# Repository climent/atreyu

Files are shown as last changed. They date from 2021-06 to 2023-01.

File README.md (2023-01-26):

# Atreyu keyboard

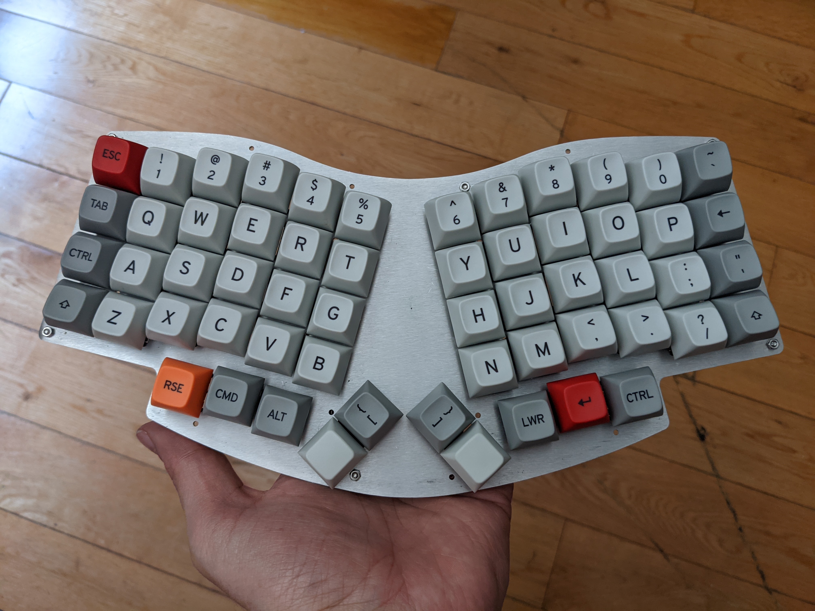
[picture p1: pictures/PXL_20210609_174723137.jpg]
A picture of the original, handwired Atreyu The original, handwired Atreyu keyboard

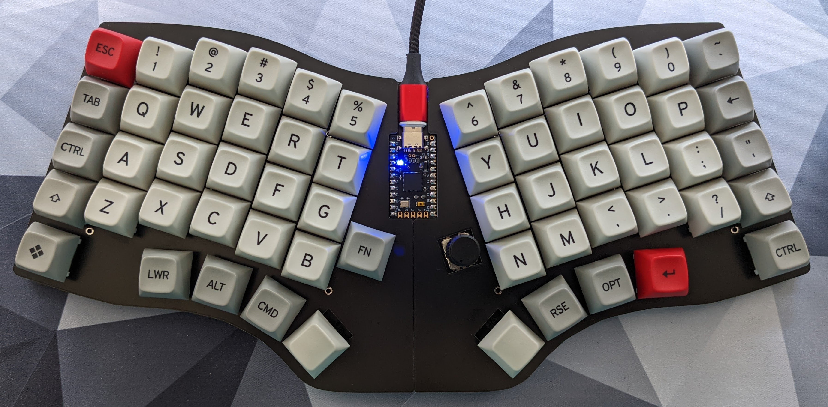
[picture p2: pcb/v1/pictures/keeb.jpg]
A picture of the Atreyu (v1) The Atreyu v1 keyboard

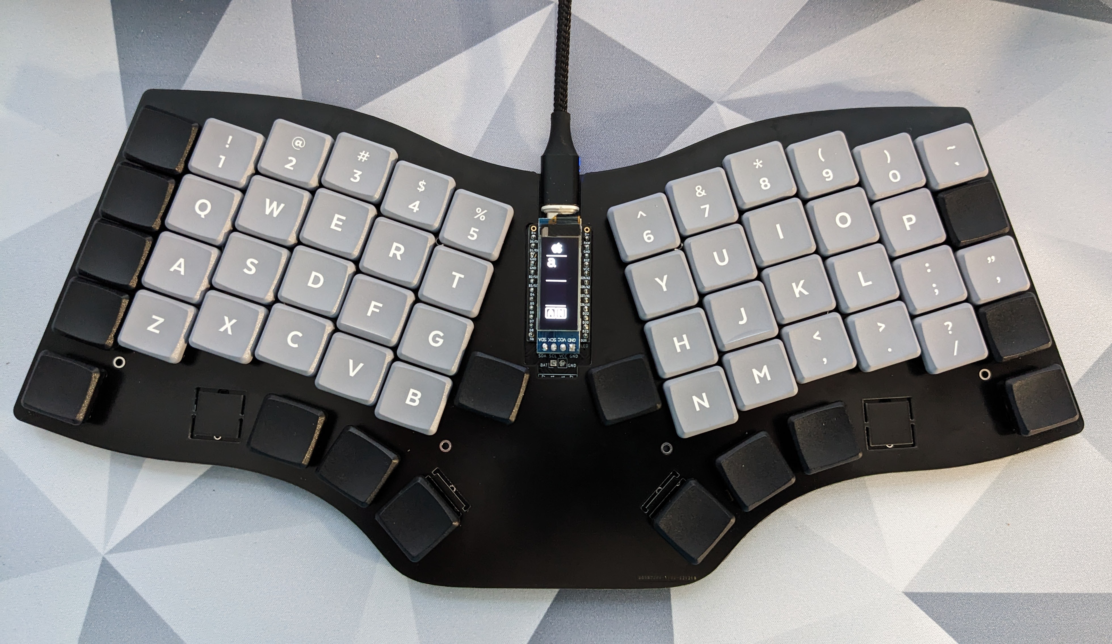
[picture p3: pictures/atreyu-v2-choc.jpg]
A picture of the Atreyu v2 Choc The Atreyu v2 Choc keyboard

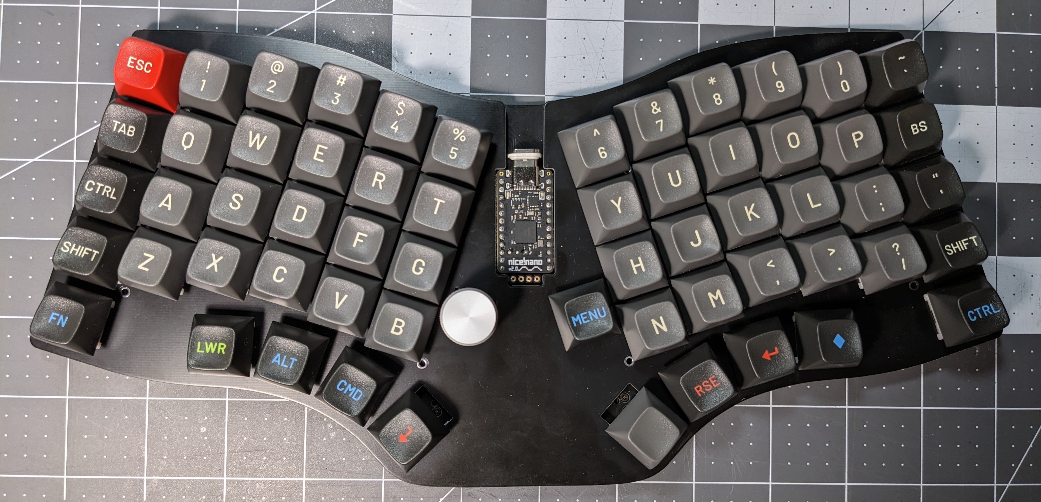
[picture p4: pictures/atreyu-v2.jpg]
A picture of the Atreyu v2 MX The Atreyu v2 Choc keyboard


It all started with a handwired Lily58fied version of the Atreis keyboard.

Based on [Dekonnection's Atreis keyboard design files](https://github.com/dekonnection/atreis),
modified to achieve the same layout in a single-piece form-factor.

## Why ?

Because the Atreis is the most convenient keyboard to take when on the go, but I thought i needed a couple of extra keys, like the Lily58.

## What happened next?

Learning KiCad was fun, and I ended up creating a new version of the keyboard on a PCB, with the option of having they inner keys as rotary encoders, and with two additional keys at the bottom of the outer columns to be pressed with the palm. In all honesty I think I could do with less keys, but using the same amount of pins in the micro controller I could have all 60 keys in the matrix defined.

In retrospect I think I could remove some keys and be happy and productive, but at the same time I enjoyed doing the design, and I like it.

## Why this name ?

Because it looks a lot like the Atreis keyboard, but with the Lily58 layout.

## How do I build one ?

You can find a [PCB](http://github.com/climent/atreyu/tree/main/pcb) for it. The board has been fully tested and the firmware is functional out of the box. A build guide is under construction.

## Can I do the handwired version?

Sure thing! The SVG files are [available](pcb/handwired/). The wiring is quite straightforward: all rows are independent, and columns are combined together across both sides (columns are connected from outside to inside). You can [check this picture](pictures/atreyu-wired.jpg?raw=true "The wires"). You just have to flash the right firmware with the right keymap, all of which are available from the link below.

# Firmware

You can find my copy of the keyboard mapping [here.](http://github.com/climent/qmk_firmware/tree/climent/keyboards/atreyu/)

There are 3 different revisions: handwired, rev1 and rev2, depending of the board you are building .

You can also find the keyboard configuration to get a working firmware for rev1 and rev2 in the [main QMK tree](http://github.com/qmk/qmk_firmware/tree/master/keyboards/atreyu/).

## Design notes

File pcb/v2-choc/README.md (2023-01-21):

# Atreyu V2 choc keyboard

A picture of the Atreyu V2 choc The Atreyu keyboard

# Changes from V1

* New options for MCUs:
  * Pro Micro: with this MCU the functionality of the keyboard is only reduced by not being able to use encoders.
  * Elite-C, Elite-Pi, Puchi, Frood: all the functioinality, i.e., OLED, encoders, all keys.
  * Nice!Nano v2: all functionality plus wireless! (Some restrictions apply)

| MCU | OLED |Encoders | Bluetooth (ZMK) | LEDs |
|---|---|---|---|---|
|ProMicro | ✅ | 🚧 | | ✅ |
|Elite-C  | ✅ | ✅ | | ✅ |
|nice!nano| 🚧 | ✅ | ✅ | ✅ |

* OLED pins for a 32x128 screen over the MCU
* Space for a battery, with power kill switch and pins for soldering the battery to the PCB, currently for a 500mAh
  * Different versions of the PCB will be released for different battery sizes.
* 5 underglow LED (SK6812Mini-E slots) as status indicators.

The new Rev2 revision is not pin-compatible with Rev1.

Due to the fact that some pins are shared across the OLED, the encoders and the LEDs, some configurations require sacrificing some features in favour of others. E.g., in a board with OLED and LEDs, one can only have one encoder.

NOTE: Elite-pi, Frood, and similar rp2040-based boards work the same way as the Elite-C board, as they have the same number of pins available.

# Firmware

You can find my copy of the keyboard mapping [here.](http://github.com/climent/qmk_firmware/tree/master/keyboards/atreyu/)

QMK firmware is available upstream, under the rev2 folder.

ZMK configuration for the Nice!nano board is available [here](https://github.com/climent/zmk-config)

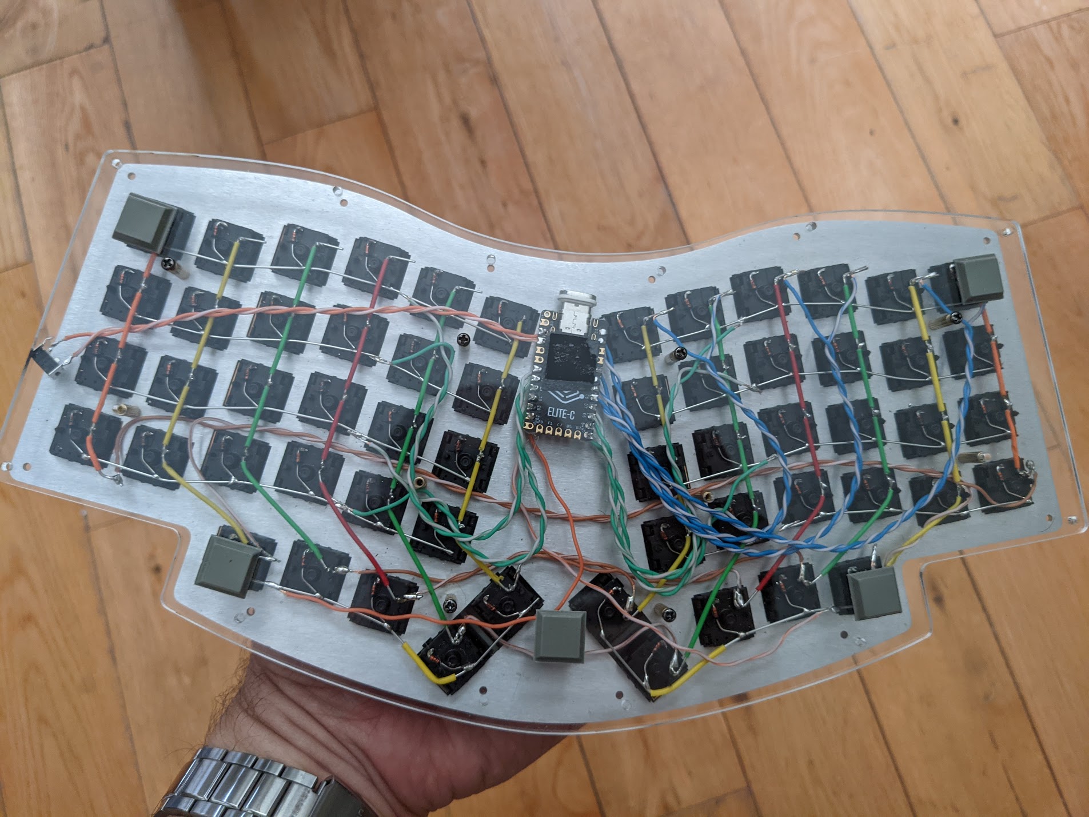
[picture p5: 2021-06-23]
pictures/atreyu-wired.jpg

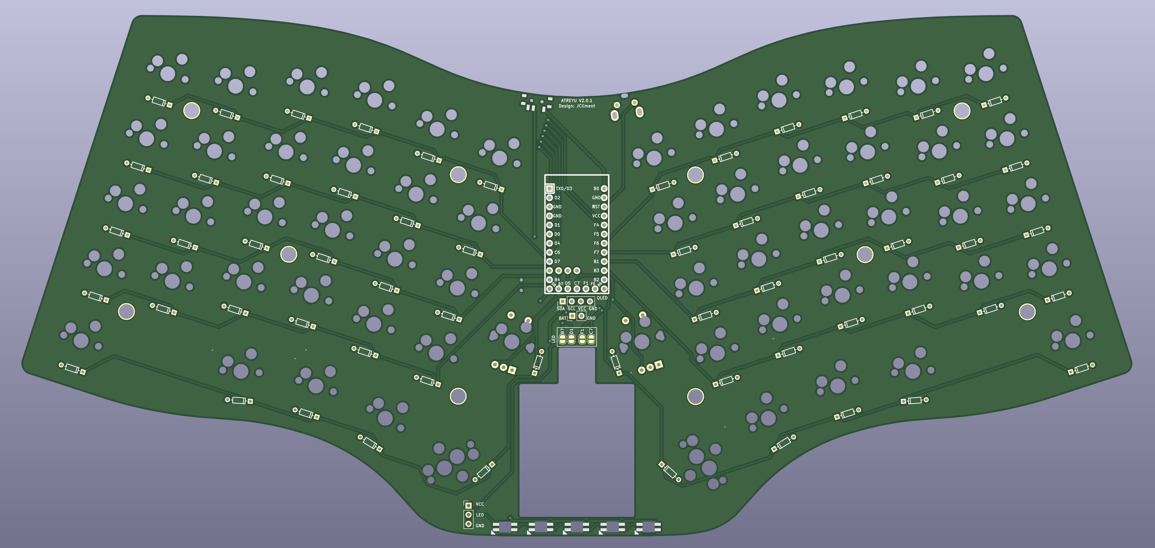
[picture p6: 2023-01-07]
pcb/v2/pictures/top.png

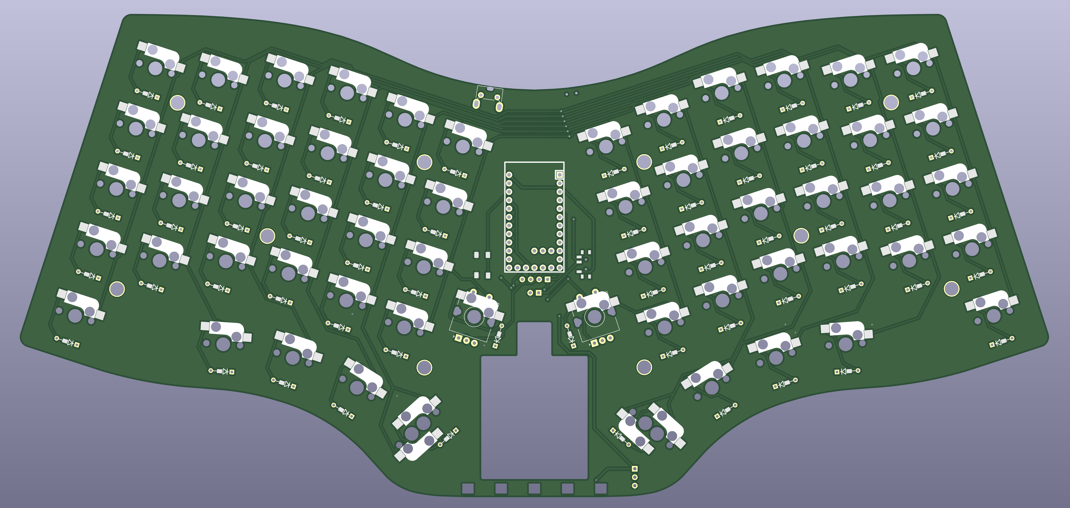
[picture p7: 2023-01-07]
pcb/v2/pictures/bottom.png

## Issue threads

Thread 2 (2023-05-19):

gerbers files for V2 (none-choc)

maxyurk, 2023-05-19:
Hi

First of all I'd like to thank you for this awesome open source keyboard.
I'm interested in building one.
My ask is if it would be possible to include the gerbers for the V2 under the sources/releases. I'm not experienced with KiCad and when I tried to create them I got an issue I couldn't resolve on my own.

Also if you're interested I can help out creating a github page for this project. I noticed a stale branch for it in the repo. https://docusaurus.io/ is a pretty good option I'm familiar with.

Thanks in advance.

climent, 2023-05-21:
Gerber files for v2 have been added to the repo. Enjoy!

maxyurk, 2023-08-04:
Thank you. It turned out great. Really happy with it.
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

climent, 2023-08-04:
Looks really nice! Hope you enjoy it!

Closed 2023-05-21.

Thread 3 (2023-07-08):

Rotary Encoder Troubleshooting

TimCummings, 2023-07-08:
Hello, and thanks for the fantastic keyboard design!

This isn't exactly an "issue", I'm just having some trouble getting rotary encoders to work and wanted to see if you had any suggestions. I have an Atreyu v2 choc PCB with a nice!nano and [EC12 encoders](https://tech.alpsalpine.com/e/products/detail/EC12E2440301/). I have the two `CONFIG_EC11` lines uncommented in the top level `atreyu.conf` file. And I can't get the encoders to do anything (I've tried volume +/- and page up/down so far; I have the same key codes on other switches and they work as expected there.)

If it were a switch, I'd check continuity across the pins with the switch pressed, but I'm less sure how to start troubleshooting a rotary encoder.

Also, the underglow status LEDs - are they used at all by default or do I need to add something in the firmware for those?

climent, 2023-07-11:
Let me figure it out and i will get back to you.

climent, 2023-07-14:
First of all, for the encoders to work with a nice!nano board, the 3 extra pins in the middle of the board need to be connected. Did you connect those?

I am right now testing support for the encoder on the right, as I had only configured the code for the encoder on the left. I will let you know once it is working correctly.

TimCummings, 2023-07-15:
> First of all, for the encoders to work with a nice!nano board, the 3 extra pins in the middle of the board need to be connected.

Is that pins 101, 102, & 107 in the screenshot here? https://nicekeyboards.com/docs/nice-nano/

climent, 2023-07-15:
Correct. The routing of the tracks needs those pins. The default configuration in the zmk-config repository here is set for the encoder on the left side.

https://github.com/climent/zmk-config/tree/5e345b4ee15ec3eaf14a35d0d8089bc64e64358b

After that I made some changes that broke the board, but I have not had the time to continue investigating.

TimCummings, 2023-07-15:
That was the issue: I overlooked those three pins. Sorry about that; thanks for your help!

The left is working great; the right works but is a little funky (seems to send both presses with a slight delay in the middle.) I'll fiddle with it some and comment back if I have any success. I was just stuck when I couldn't get either of them to do anything - which makes sense if they weren't even connected to the controller! :facepalm:

Closed 2023-07-15.

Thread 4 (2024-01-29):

Is a build guide still in the works?

Richiban, 2024-01-29:
I've started a build of the Atreyu and it's the first keyboard I'll be building from scratch.

I've got the PCB and have soldered on the hotswap sockets and the socket for the controller; I'm a bit lost, however, with everything else. I've got a nice!nano because I'm planning a wireless build but I'm happy to stick with wired to get it up and running and will upgrade it later. Apologies if these questions are answerable by looking at the KiCad files, but that's rather beyond my ability at the moment.

For the wired version I need to know:
* Where should I put the reset switch? No switch is visible in the photos of the complete keyboard.
* What kind of diodes do I need? The PCB seems to have symbols for SMD diodes on one side of the board and through-hole on the other. Do I need both?
* The socket for the controller seems to have more pins than exist on the nice!nano (i.e. there's one shorter bank on the "bottom" of the controller that the nice!nano doesn't have). Am I giving anything up using nice!nano?

Eventually, to make it wireless, I need to know:
* Where do I put the battery switch?
* Where do I put the battery connector?

Thank you very much for releasing this keyboard design; it's by far my favourite I've ever seen! I currently have a pre-built Sofle that I love, but I'm looking to go unsplit / unibody.

climent, 2024-01-29:
Hi Richard.

First of all, thanks for reaching out. I understand building your first
keyboard may be a daunting task, and i will try to help you as much as i
can.

What version of the PCB did you use? The latest one (2.0.1) should be the
one to use, as it fixed a couple of bugs on the previous ones. Can you
confirm you have that one?

For the reset switches, there are 2 options: a lateral push switch,
available at
https://splitkb.com/collections/keyboard-parts/products/reset-buttons, or a
flat switch, like this one: https://www.digikey.ie/short/ntjm0mnn

The side button goes here:

[image: Screenshot 2024-01-29 at 14.08.24.png]

While the flat button goes here:

[image: Screenshot 2024-01-29 at 14.08.55.png]

There is also a battery switch, available from here:
https://splitkb.com/products/wireless-controller-expansion-bundle

It goes either here:

[image: Screenshot 2024-01-29 at 14.10.02.png]

Or here:

[image: Screenshot 2024-01-29 at 14.10.21.png]

I recommend using the internal ones, as they are accessible from the 2
holes in the bottom plate, and they look nicer in my opinion.

The diodes are standard 1N4148W signal diodes, available here:
https://splitkb.com/collections/keyboard-parts/products/smd-diodes

They can be soldered on the bottom side of the board, with the side of the
line pointing in the direction of the arrow. The Soufflé build guide
https://github.com/climent/SouffleKeyboard/blob/main/docs/build_guide.md
has some photos on how to set them up.

The 3 extra pins in the middle of the nice nano are for rotary encoders,
but they are currently broken in the ZMK software, so you don't miss much,
right now.

If you want to have the encoders, then you have to move the battery to the
big hole in the board. It has space for a 500 mAh battery.

It goes soldered to the BAT/GND pins here:

[image: Screenshot 2024-01-29 at 14.16.31.png]

Let me know if you have any more questions.

On Mon, 29 Jan 2024 at 13:13, Richard Gibson ***@***.***>
wrote:

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

--
climent () gmail ! com

Richiban, 2024-01-29:
Thank you so much for your reply @climent, unfortunately the images have not come through in your comment.

There's no rush, but if you have time to come back and edit your comment with the uploaded images I'd be very grateful.

Thanks!

climent, 2024-01-29:
You can provide an email address to "climent () gmail ! com" and i
can forward you the email with the images.

On Mon, 29 Jan 2024 at 15:06, Richard Gibson ***@***.***>
wrote:

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

--
climent () gmail ! com

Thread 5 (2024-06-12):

Bill of Materials for some designs?

gagbo, 2024-06-12:
Hello,

I’m a bit interested by the board, but I never started anything from non-kit. I think I can get the PCB done, and the diodes are probably always the same, but there are still a a few unknowns (at least for the v2 choc I’m eyeing):
- What kind of battery do you expect to fit there?
- Do you have a source/plan to get the case done?
- Is there a way to fit hot swap sockets you think?

Thanks for the inspiring design anyway!

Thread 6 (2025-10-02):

Having issue with inner thumb buttons not registering

mmmintdesign, 2025-10-02:
I built Atreyu v2 choc, with 0xCB Helios as the controller. No lcd, no encoder.

But for some reason, inner thumb buttons do not register (space and enter with the default layout).

Tried:
- software side: remapping enter and space to basic letters, tried Atreyu ver1 for qmk
- hardware side: resoldering, changing diodes, and even using a second PCB, yet nothing seems to fix it.

The QMK flash command that I used was
`qmk flash -e CONVERT_TO=helios -kb atreyu/rev2 -km default`.

PCB Gerber file was modified, removed/filled the hole for the battery. I can post the gerber file if you think it's causing the issue?

Closed 2025-10-02.

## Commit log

2021-06-11 Photos of the board.
2021-06-22 Added PCB link.
2021-06-23 Wired picture added and README updated.
2022-02-19 Added PCB v1.
    [atreyu-pcb2-B_Cu.gbl, atreyu-pcb2-B_Mask.gbs, atreyu-pcb2-B_Paste.gbp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]
2022-02-20 Added PCB for the original atreyu board.
    [atreyu.kicad_sch]
2022-02-20 Added top and bottom plates for the v0.1 case.
    [bottom.kicad_pcb, top.kicad_pcb]
2022-02-20 Added top and bottom pictures for v1, and other small changes.
    [atreyu-pcb2-B_Cu.gbl, atreyu-pcb2-B_Mask.gbs, atreyu-pcb2-B_Paste.gbp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]
2022-02-20 Added png for the pcb
2022-03-12 Rerouted reset button conflict.
2022-03-12 Top case pcb.
    [pcb-case.kicad_pcb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]
2022-03-12 Fixed reset button, take 2.
    [atreyu-pcb2.kicad_sch]
2022-03-20 Added complete case PCB.
    [pcb-case-complete.kicad_pcb]
2022-03-20 Janitorial cleanup.
    [untitled-B_Cu.gbl, untitled-B_Mask.gbs, untitled-B_Paste.gbp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]
2022-04-01 Updated casing plates.
    [pcb-case-bottom.kicad_pcb, pcb-case-complete.kicad_pcb, pcb-case.kicad_pcb]
2023-01-02 Added v2 choc release.
    [v2-choc.kicad_sch]
2023-01-04 Added cases for V2 and V2-choc.
    [pcb-case-bottom.kicad_pcb, pcb-case-complete-no-oled.kicad_pcb, pcb-case-complete.kicad_pcb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]
2023-01-07 Release of Atrety V2 MX.
    [atreyu-pcb2.kicad_sch, pcb-case-bottom.kicad_pcb]
2023-01-15 Removed old files from v2 case dir.
2023-01-26 Reorg of some files, updated README.
    [bottom.kicad_pcb, top.kicad_pcb]
2023-03-11 Added extra power connectors, and blocked entries in upper case plate.
    [pcb-case-complete.kicad_pcb]
2023-05-18 Reroute possibly problematic track.
2023-05-21 Added gerbers for v2.
2023-05-21 fixed small issues for the v2 case.
    [pcb-case-bottom.kicad_pcb, pcb-case-complete.kicad_pcb]
